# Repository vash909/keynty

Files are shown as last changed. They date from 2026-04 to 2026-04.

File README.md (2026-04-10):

# KEYNTY CMOS CW Keyer
A CW keyer based on the original Minty Keyer project by K4ICY https://www.k4icy.com/weekend_radio_minty_kool_keyer.html

Improvements:
- Removed diodes OR
- Removed BJT keying for OR matrix
- Added CMOS OR Gates
- Changed all the logic gates to Low-Voltage (3.6V max)
- Added sidetone buzzer
- Added power LED
- Added alkaline battery holder (3V AA size x2)
- Reduced overall power consumption
- Added a switch for switching iambic mode (A/B)
- Added a switch for sidetone enable

PCB can be mounted directly on the back of the battery holder.

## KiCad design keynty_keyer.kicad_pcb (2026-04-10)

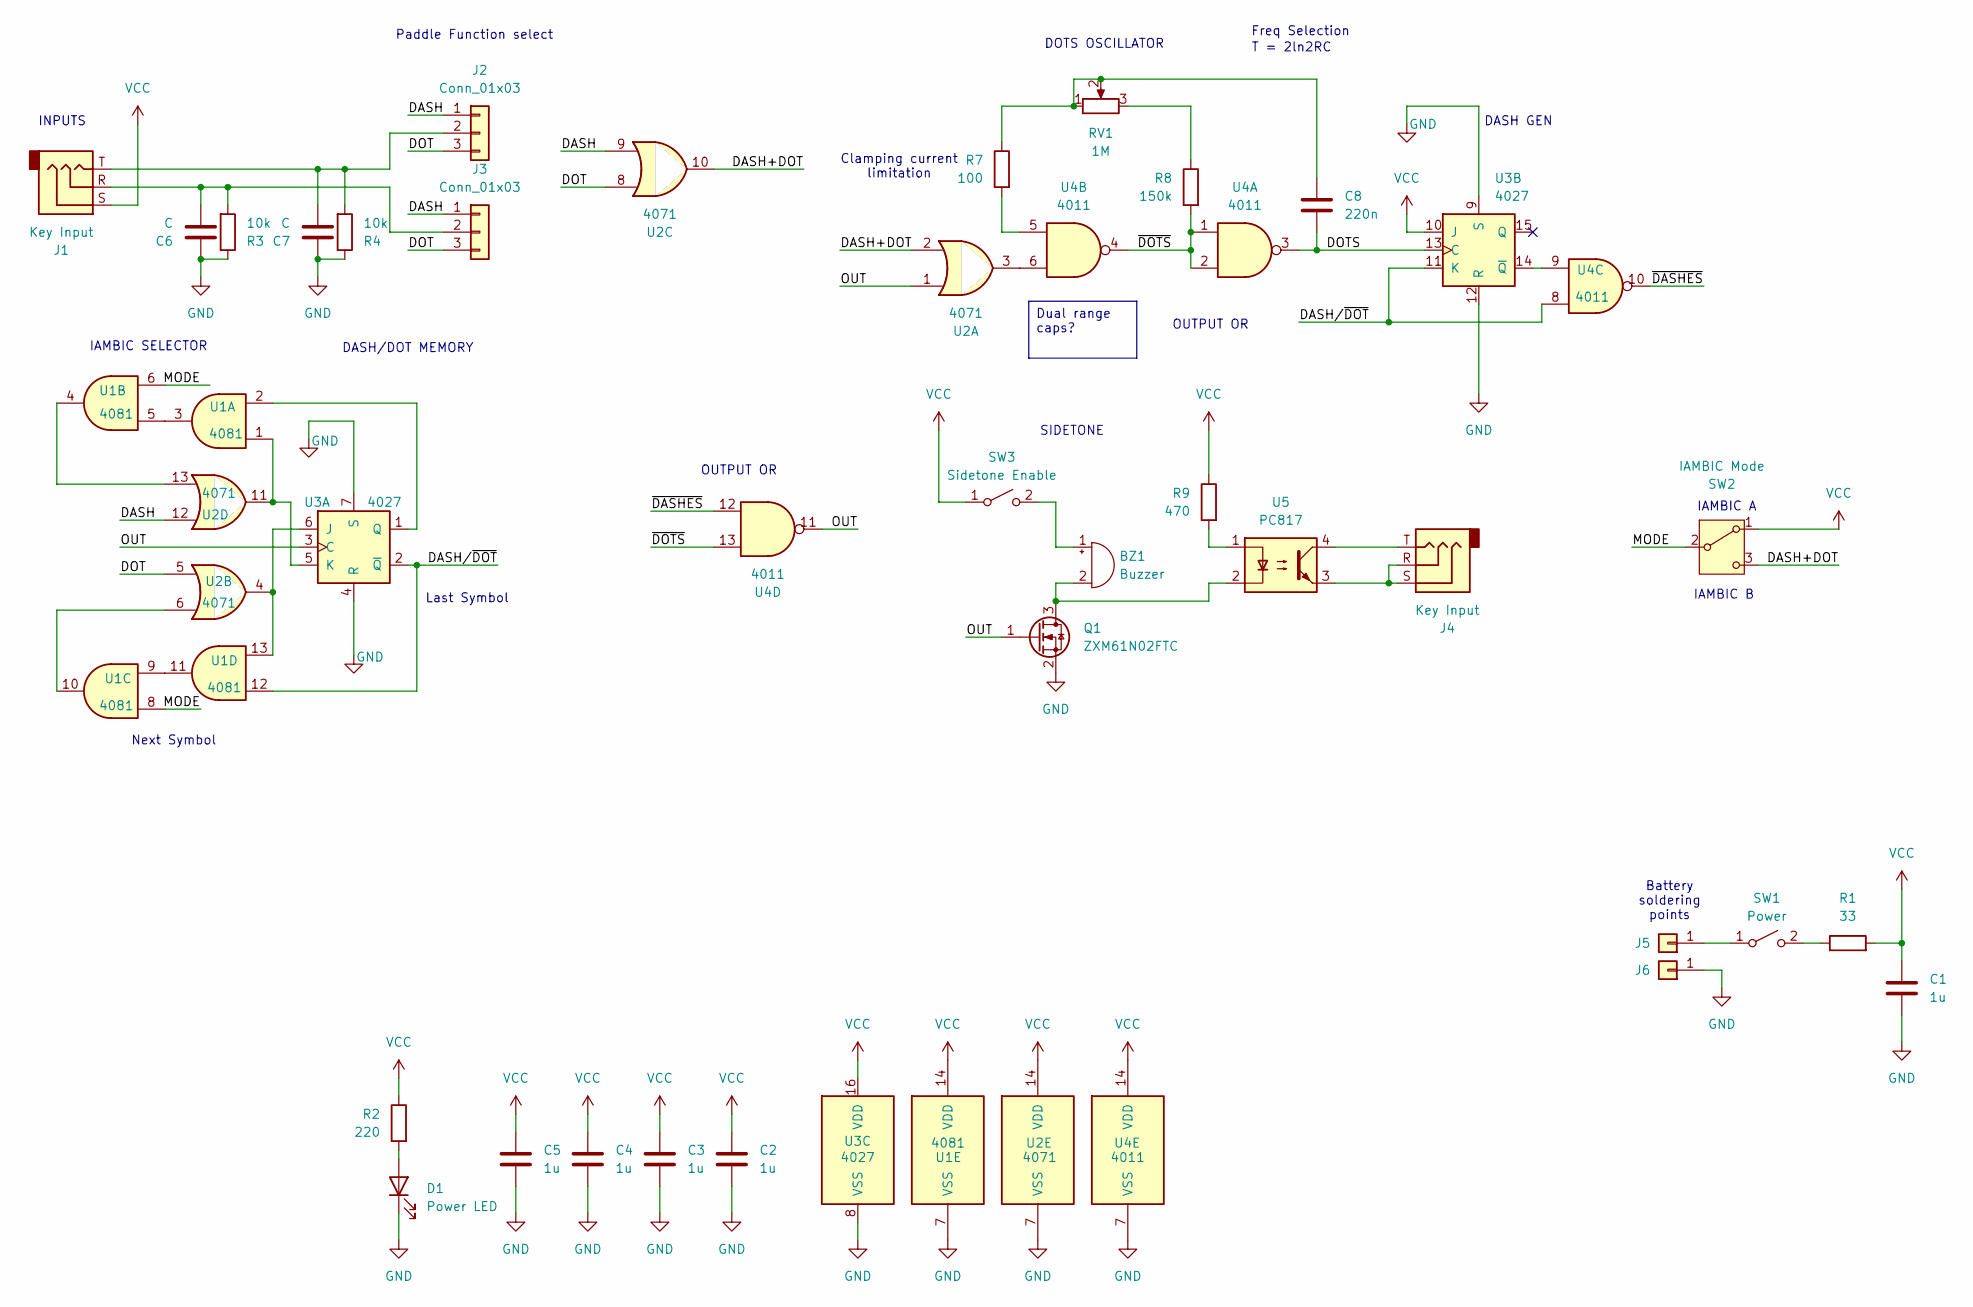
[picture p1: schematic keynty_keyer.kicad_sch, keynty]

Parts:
BZ1: Buzzer; Buzzer_12x9.5RM7.6
C1, C2, C3, C4, C5: 1u; C_0805_2012Metric
C6, C7: C; C_0603_1608Metric
C8: 220n; C_0603_1608Metric
D1: Power LED; LED_0603_1608Metric
J1, J4: Key Input; Jack_3.5mm_CUI_SJ1-3513N_Horizontal
J2, J3: Conn_01x03; PinHeader_1x03_P2.54mm_Vertical
J5, J6: Conn_01x01; TestPoint_THTPad_2.0x2.0mm_Drill1.0mm
Q1: ZXM61N02FTC; SOT-23
R1: 33; R_0603_1608Metric
R2: 220; R_0603_1608Metric
R3, R4: 10k; R_0603_1608Metric
R7: 100; R_0603_1608Metric
R8: 150k; R_0603_1608Metric
R9: 470; R_0603_1608Metric
RV1: 1M; Potentiometer_Alps_RK09K_Single_Vertical
SW1: Power; SW_Slide_SPDT_Straight_CK_OS102011MS2Q
SW2: IAMBIC Mode; SW_Slide_SPDT_Straight_CK_OS102011MS2Q
SW3: Sidetone Enable; SW_Slide_SPDT_Straight_CK_OS102011MS2Q
U1: 4081; SOIC-14_3.9x8.7mm_P1.27mm
U2: 4071; SOIC-14_3.9x8.7mm_P1.27mm
U3: 4027; SOIC-16_3.9x9.9mm_P1.27mm
U4: 4011; SOIC-14_3.9x8.7mm_P1.27mm
U5: PC817; DIP-4_W8.89mm_SMDSocket_LongPads

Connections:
/DASH: J2.1, J3.1, U2.9, U2.12
/DASH+DOT: SW2.3 (C), U2.2, U2.10
/DASH/~DOT: U1.12, U3.2 (~Q), U3.11 (K), U4.8
/DOT: J2.3, J3.3, U2.5, U2.8
/DOTS: C8.2, U3.13 (C), U4.3
/MODE: SW2.2 (B), U1.6, U1.8
/OUT: Q1.1 (G), U2.1, U3.3 (C), U4.11
/~DASHES: U4.10, U4.12
/~DOTS: R8.2, U4.1, U4.2, U4.4, U4.13
GND: C1.2, C2.2, C3.2, C4.2, C5.2, C6.1, C7.1, D1.1 (K), J6.1 (Pin_1_1), Q1.2 (S), R3.1, R4.1, U1.7 (VSS), U2.7 (VSS), U3.4 (R), U3.7 (S), U3.8 (VSS), U3.9 (S), U3.12 (R), U4.7 (VSS)
unnamed: BZ1.1 (+), SW3.2 (B)
unnamed: BZ1.2 (-), Q1.3 (D), U5.2
unnamed: C8.1, R7.1, RV1.1, RV1.2
unnamed: D1.2 (A), R2.2
unnamed: C7.2, J1.T, J2.2, R4.2
unnamed: C6.2, J1.R, J3.2, R3.2
unnamed: J4.R, J4.S, U5.3
unnamed: J4.T, U5.4
unnamed: J5.1 (Pin_1_1), SW1.1 (A)
unnamed: R7.2, U4.5
unnamed: R8.1, RV1.3
unnamed: R9.2, U5.1
unnamed: R1.1, SW1.2 (B)
unnamed: U1.3, U1.5
unnamed: U1.4, U2.13
unnamed: U1.10, U2.6
unnamed: U1.9, U1.11
unnamed: U2.3, U4.6
unnamed: U1.13, U2.4, U3.6 (J)
unnamed: U1.1, U2.11, U3.5 (K)
unnamed: U1.2, U3.1 (Q)
unnamed: U3.14 (~Q), U4.9
VCC: C1.1, C2.1, C3.1, C4.1, C5.1, J1.S, R1.2, R2.1, R9.1, SW2.1 (A), SW3.1 (A), U1.14 (VDD), U2.14 (VDD), U3.10 (J), U3.16 (VDD), U4.14 (VDD)

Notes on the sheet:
Freq Selection
IAMBIC SELECTOR
DASH/DOT MEMORY
Battery soldering points
OUTPUT OR
DASH GEN
Last Symbol
IAMBIC B
T = 2ln2RC
SIDETONE
INPUTS
Paddle Function select
Next Symbol
Clamping current limitation
DOTS OSCILLATOR
IAMBIC A
Dual range caps?

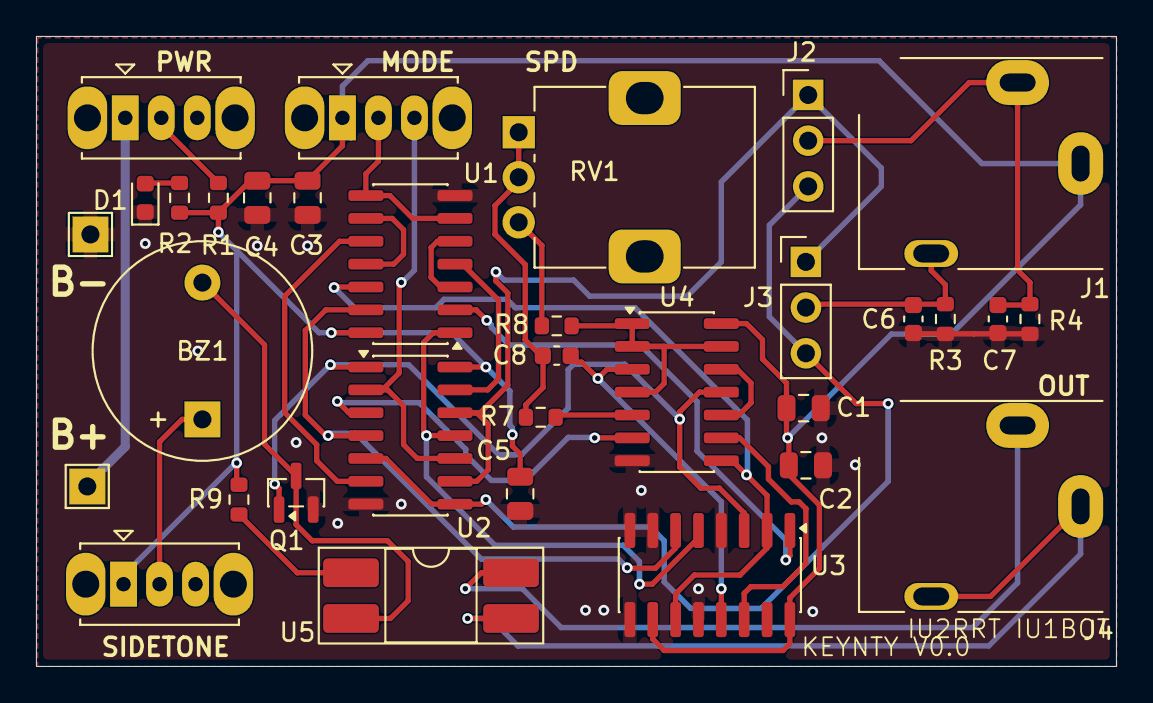
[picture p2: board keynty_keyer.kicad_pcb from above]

Board: 2 copper layers, 60.0 x 35.0 mm, 33 parts (0 on the bottom side), 33 nets.

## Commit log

2026-04-03 created files
    [keynty_keyer.kicad_pcb, keynty_keyer.kicad_sch]
2026-04-03 added power conditioning
    [keynty_keyer.kicad_sch]
2026-04-05 First Draft of schematic, starting from minty keyer, removed all the diode logic, changed output and input stages
    [keynty_keyer.kicad_sch]
2026-04-07 added selector dot/dash, verified oscillator frequencies, added buzzer placeholder
    [keynty_keyer.kicad_sch]
2026-04-07 added matteo sidetononi e matteo powerleddoni
    [keynty_keyer.kicad_sch]
2026-04-07 corrected IAMBIC selector,added footprints, first PCB Draft
    [keynty_keyer.kicad_pcb, keynty_keyer.kicad_sch]
2026-04-07 changed output jack connections, corrected mosfet
    [keynty_keyer.kicad_pcb, keynty_keyer.kicad_sch]
2026-04-07 added reference datasheets in BOM
    [keynty_keyer.kicad_sch]
2026-04-07 correct powwer supply inverted
    [keynty_keyer.kicad_pcb, keynty_keyer.kicad_sch]
2026-04-07 changed pull down ok the inputs
    [keynty_keyer.kicad_pcb, keynty_keyer.kicad_sch]
2026-04-10 refdes position adjusted and clean-up back silkscreen
    [keynty_keyer.kicad_pcb]
2026-04-10 added missing resistor values for pull-down and opto drive
    [keynty_keyer.kicad_sch]
2026-04-10 corrected battery footprint, added QR, changed minor silkscreen
    [keynty_keyer.kicad_pcb, keynty_keyer.kicad_sch]
2026-10-31 sto scrivendo il commit
2026-10-31 added LCSC number for integrated circuits, leds and capacitors
2026-11-01 Remove schematic review PDF
